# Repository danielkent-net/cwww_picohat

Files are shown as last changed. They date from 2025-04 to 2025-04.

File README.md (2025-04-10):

# cwww\_picohat: Pi Pico based Dual Cool/Warm LED Lamp Controller

A Raspberry Pi Pico/Pi Pico W based controller for dual cool white / warm
white common anode LED lamps.

|KiCAD Render | Assembled Version|
|---|---|
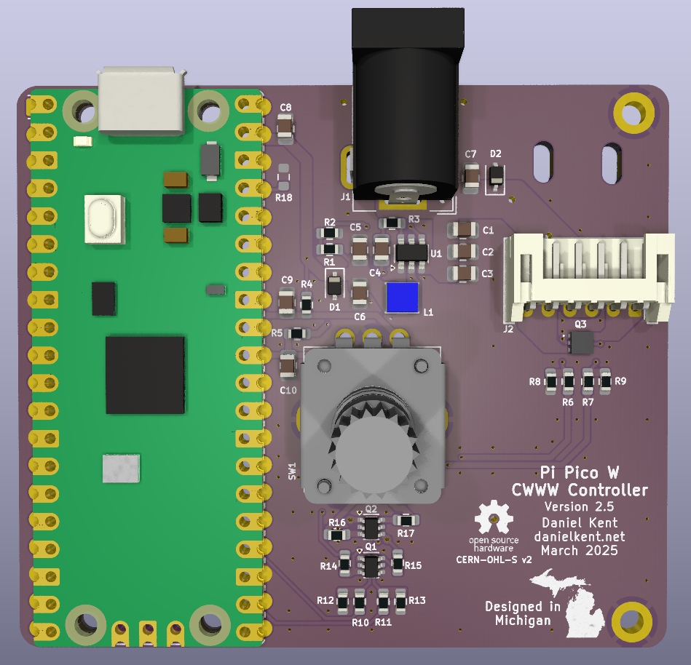
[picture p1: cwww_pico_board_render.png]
Render of the CWWW Pico LED controller, board variant
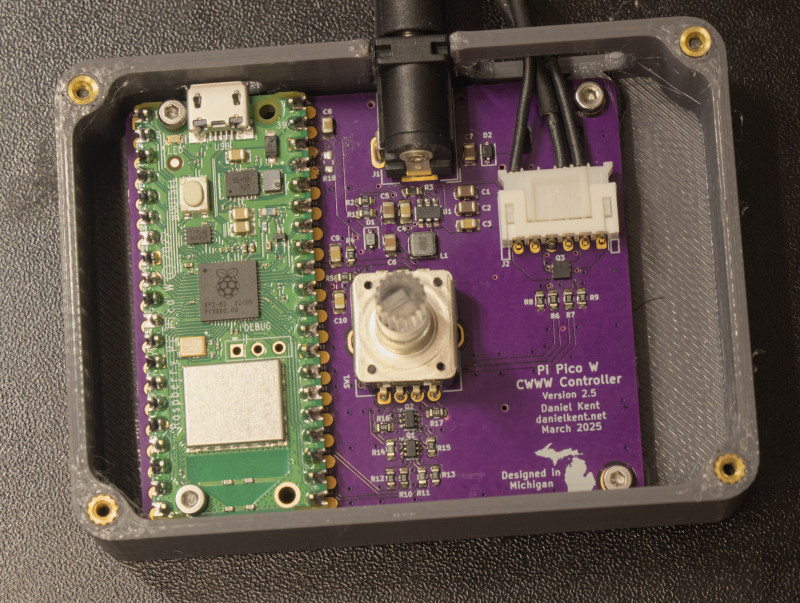
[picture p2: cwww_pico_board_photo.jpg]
Photograph of CWWW Pico LED controller, board variant
|  |  |

This repository contains two variants: the original "hat" based design, which
is smaller and contains a connector for a dedicated user I/O board, and a
larger "board" variant that puts everything on a flat board. The board
variant is a much more mature design and is recommended if you want to try
making this yourself.

This board was designed to work with
[ESPHome](https://github.com/esphome/esphome), but could be easily programmed
with other software tools.

# License

[The hardware is licensed under the CERN Open Hardware License Version
2 - Strongly Reciprocal](LICENSE).

[ESPHome configurations are licensed under the MIT license](LICENSE-SW).

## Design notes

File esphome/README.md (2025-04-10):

# ESPHome configurations for CWWW Pico Hat/Board

Note: the CWWW Pico Hat configuration has not been tested, as that design has
been retired. Use at your own risk.

Remember to edit or replace secrets.yaml.

These configurations were tested on the esphome version 2024.12.4.

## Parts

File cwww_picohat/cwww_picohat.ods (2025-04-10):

Source: | /home/silver/Projects/cwww_picohat/cwww_picohat/cwww_picohat.kicad_sch
Date: | Tue 07 Feb 2023 07:38:26 PM EST
Tool: | Eeschema 6.0.2+dfsg-1
Generator: | /usr/share/kicad/plugins/bom_csv_grouped_by_value_with_fp.py
Component Count Ea: | 32
Board Count | 2
Ref | Qnty Per | Qnty Total | Cost Ea. | Cost Total | Value | Cmp name | Footprint | Description | Vendor | URL
C1, C2, C7, C1b | 4 | 8 | $0.20 | $1.60 | 10uF | C | Capacitor_SMD:C_0805_2012Metric_Pad1.18x1.45mm_HandSolder | 10uF 0805 Unpolarized Capactitor | Digikey | https://www.digikey.com/en/products/detail/samsung-electro-mechanics/CL21A106KAFN3NE/3888548
C3, | 1 | 2 | $0.23 | $0.46 | 1uF | C | Capacitor_SMD:C_0805_2012Metric_Pad1.18x1.45mm_HandSolder | 1uF 0805 Unpolarized Capactitor | Digikey | https://www.digikey.com/en/products/detail/kyocera-avx/08053C105MAT4A/8107686
C4, | 1 | 2 | $0.10 | $0.20 | .1uF | C | Capacitor_SMD:C_0603_1608Metric_Pad1.08x0.95mm_HandSolder | .1uF 0805 Unpolarized Capactitor | Digikey | https://www.digikey.com/en/products/detail/kyocera-avx/08055C104KAT4A/6816312
C5, C6, | 2 | 4 | $0.33 | $1.32 | 22uF | C | Capacitor_SMD:C_0805_2012Metric_Pad1.18x1.45mm_HandSolder | 22uF 0805 Unpolarized Capactitor | Digikey | https://www.digikey.com/en/products/detail/samsung-electro-mechanics/CL21A226KOQNNNG/3894433
J1, | 1 | 2 | $0.17 | $0.34 | Conn_01x02 | Conn_01x02 | Connector_JST:JST_PH_S2B-PH-K_1x02_P2.00mm_Horizontal | JST PH Connector, 2mm Pitch, Horizontal, 2 Pin | Digikey | https://www.digikey.com/en/products/detail/jst-sales-america-inc/S2B-PH-K-S-LF-SN/926626
J2, | 1 | 2 | $0.31 | $0.62 | Conn_01x06 | Conn_01x06 | Connector_JST:JST_PH_S6B-PH-K_1x06_P2.00mm_Horizontal | JST PH Connector, 2mm Pitch, Horizontal, 6 Pin | Digikey | https://www.digikey.com/en/products/detail/jst-sales-america-inc/S6B-PH-K-S-LF-SN/926630
J3, J1b | 2 | 4 | $0.36 | $1.44 | Conn_01x06 | Conn_01x06 | Connector_JST:JST_PH_B6B-PH-K_1x06_P2.00mm_Vertical | JST PH Connector, 2mm Pitch, Vertical, 6 Pin | Digikey | https://www.digikey.com/en/products/detail/jst-sales-america-inc/B6B-PH-K-S-LF-SN/926615
L1, | 1 | 2 | $0.61 | $1.22 | 2.2uH | L | Inductor_SMD:L_1210_3225Metric_Pad1.42x2.65mm_HandSolder | 2.2uH 1210 Inductor | Digikey | https://www.digikey.com/en/products/detail/murata-electronics/LQM31PN2R2M00L/2594617
Q1, Q2, | 2 | 4 | $0.44 | $1.76 | NXV55UN | Q_NMOS_DSG | Package_TO_SOT_SMD:SOT-23 | NXV55UN N-MOSFET transistor, drain/source/gate | Digikey | https://www.digikey.com/en/products/detail/murata-electronics/DFE322512F-2R2M-P2/9815914
R1 | 1 | 2 | $0.10 | $0.20 | 33.2k | R | Resistor_SMD:R_0603_1608Metric_Pad0.98x0.95mm_HandSolder | 33.2 kOhm 0603 Resistor | Digikey | https://www.digikey.com/en/products/detail/panasonic-electronic-components/ERJ-3EKF3322V/196299
R2, R4, R6 | 3 | 6 | $0.10 | $0.60 | 10k | R | Resistor_SMD:R_0603_1608Metric_Pad0.98x0.95mm_HandSolder | 10 kOhm 0603 Resistor | Digikey | https://www.digikey.com/en/products/detail/panasonic-electronic-components/ERJ-3EKF1002V/196066
R4, R5 | 2 | 4 | $0.10 | $0.40 | 10 | R | Resistor_SMD:R_0603_1608Metric_Pad0.98x0.95mm_HandSolder | 10 Ohm 0603 Resistor | Digikey | https://www.digikey.com/en/products/detail/panasonic-electronic-components/ERJ-3EKF10R0V/196065
U2, | 1 | 2 | $1.49 | $2.98 | TPS565201 | TPS565208 | Package_TO_SOT_SMD:SOT-23-6 | TPS565208 5A Voltage Regulator, SOT-23-6 | Digikey | https://www.digikey.com/en/products/detail/texas-instruments/TPS565208DDCR/7776393
SW1, SW2, SW3, SW4, | 4 | 8 | $0.35 | $2.80 | SW_Push | SW_Push | Button_Switch_SMD:SW_Push_1P1T_NO_6x6mm_H9.5mm | Push button switch, generic, two pins | Digikey | https://www.digikey.com/en/products/detail/te-connectivity-alcoswitch-switches/FSM6JSMA/525822
PCB1 | 1 | 2 | $2.50 | $5.00 | CWWW_Hat PCB | Pico_Base_Hat_Antenna_Gap | picolamp:Partial Pico Hat with Antenna Gap | Pi Pico W CWWW Hat PCB | OSHPark
Mask1 | 1 | 1 |  | $0.00
PCB2 | 1 | 2 | $1.42 | $2.83 | CWWW_Buttons PCB |  |  | Pi Pico W CWWW Buttons Board PCB | OSHPark
Mask2 | 1 | 1 |  | $0.00
Pins_Pico | 1 | 2 | $1.75 | $3.50
Pins_Hat | 1 | 2 | $1.75 | $3.50 |  |  |  |  | Sparkfun | https://www.sparkfun.com/products/115
 |  |  | Total | $23.77 |  |  |  |  | Sparkfun | https://www.sparkfun.com/products/17907
 |  |  | Total Ea | $11.89

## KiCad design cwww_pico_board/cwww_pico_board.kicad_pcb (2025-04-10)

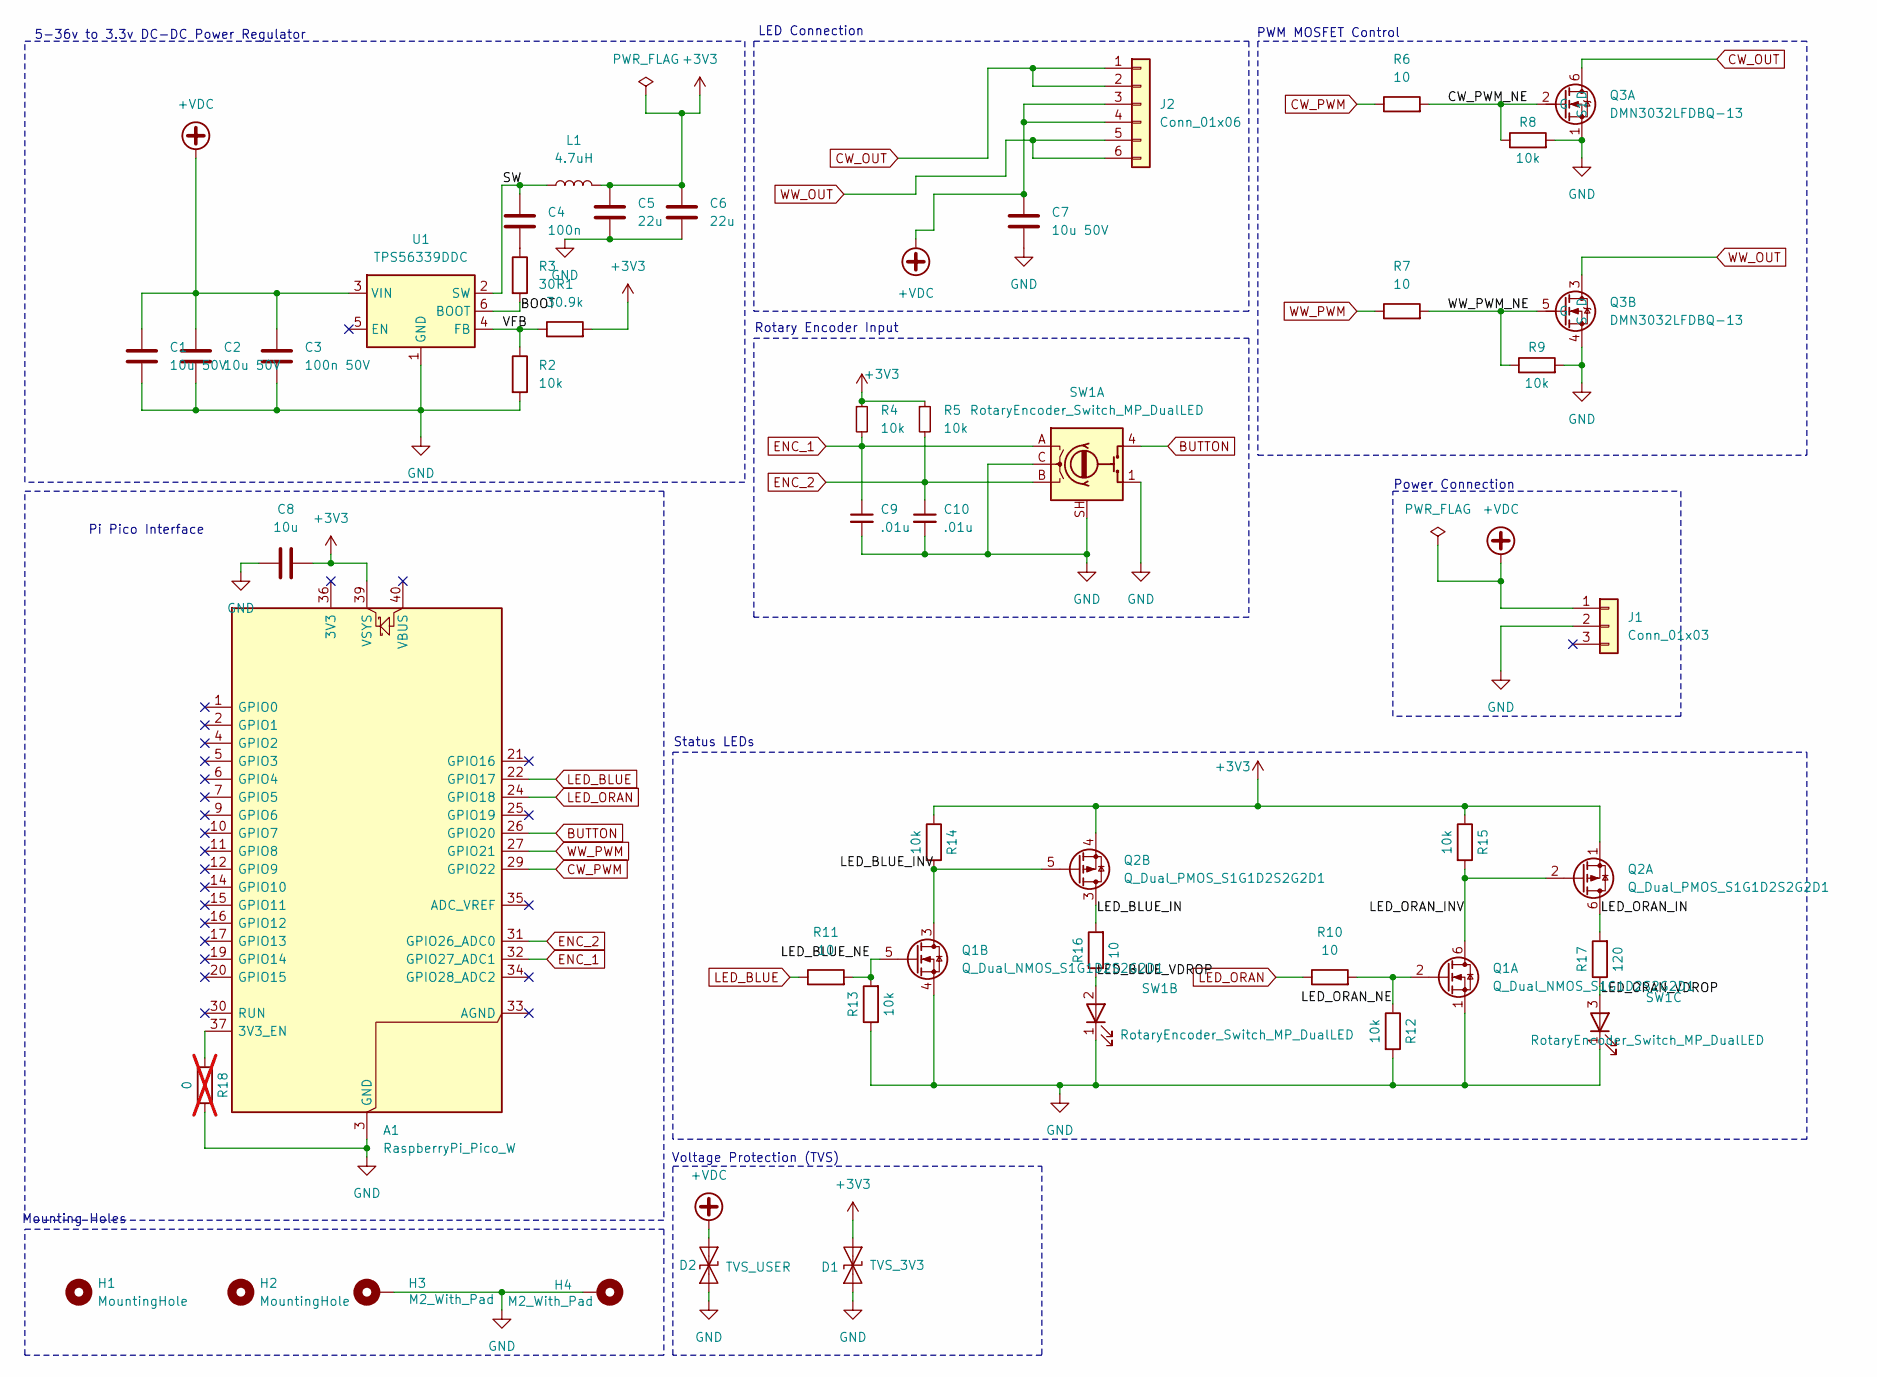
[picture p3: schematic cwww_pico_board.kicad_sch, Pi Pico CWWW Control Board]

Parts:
A1: RaspberryPi_Pico_W; RaspberryPi_Pico_Common_MountingHoles
C1, C2, C7: 10u 50V; C_0805_2012Metric
C3: 100n 50V; C_0805_2012Metric
C4: 100n; C_0805_2012Metric
C5, C6: 22u; C_0805_2012Metric
C8: 10u; C_0805_2012Metric
C9, C10: .01u; C_0805_2012Metric
D1: TVS_3V3; D_SOD-323
D2: TVS_USER; D_SOD-323
H1, H2: MountingHole; ZipTieHole_3.8mm
H3, H4: M2_With_Pad; MountingHole_2.2mm_M2_DIN965_Pad
J1: Conn_01x03; BarrelJack_Wuerth_6941xx301002_ShortOverhang
J2: Conn_01x06; JST_PH_S6B-PH-K_1x06_P2.00mm_Horizontal
L1: 4.7uH; INDPM3015X150N
Q1: Q_Dual_NMOS_S1G1D2S2G2D1
Q2: Q_Dual_PMOS_S1G1D2S2G2D1; SOT-363_SC-70-6
Q3: DMN3032LFDBQ-13; DMN3032LFDBQ13_OSHPark; Mouser Part Number 621-DMN3032LFDBQ-13
R1: 30.9k; R_0603_1608Metric
R2, R4, R5, R8, R9, R12, R13, R14, R15: 10k; R_0603_1608Metric
R3: 30; R_0603_1608Metric
R6, R7, R10, R11, R16: 10; R_0603_1608Metric
R17: 120; R_0603_1608Metric
R18: 0; R_0603_1608Metric; not fitted
SW1: RotaryEncoder_Switch_MP_DualLED; RotaryEncoder_Bourns_Vertical_PEL12D-4xxxF-Sxxxx
U1: TPS56339DDC; SOT-23-6

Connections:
+3V3: A1.39 (VSYS), C5.1, C6.1, C8.1, D1.1 (A1), L1.2, Q2.1 (S), Q2.4 (S), R1.2, R4.1, R5.1, R14.1, R15.1
+VDC: C1.1, C2.1, C3.1, C7.1, D2.1 (A1), J1.1, J2.3, J2.4, U1.3 (VIN)
/BOOT: R3.2, U1.6 (BOOT)
/CW_PWM_NE: Q3.2 (G), R6.2, R8.1
/LED_BLUE_IN: Q2.3 (D), R16.2
/LED_BLUE_INV: Q1.3 (D), Q2.5 (G), R14.2
/LED_BLUE_NE: Q1.5 (G), R11.2, R13.2
/LED_BLUE_VDROP: R16.1, SW1.2 (A_LED1)
/LED_ORAN_IN: Q2.6 (D), R17.2
/LED_ORAN_INV: Q1.6 (D), Q2.2 (G), R15.2
/LED_ORAN_NE: Q1.2 (G), R10.2, R12.1
/LED_ORAN_VDROP: R17.1, SW1.3 (A_LED2)
/SW: C4.1, L1.1, U1.2 (SW)
/VFB: R1.1, R2.1, U1.4 (FB)
/WW_PWM_NE: Q3.5 (G), R7.2, R9.1
BUTTON: A1.26 (GPIO20), SW1.4 (S1)
CW_OUT: J2.1, J2.2, Q3.6 (D)
CW_PWM: A1.29 (GPIO22), R6.1
ENC_1: A1.32 (GPIO27_ADC1), C9.1, R4.2, SW1.A
ENC_2: A1.31 (GPIO26_ADC0), C10.1, R5.2, SW1.B
GND: A1.3 (GND), A1.8 (GND), A1.13 (GND), A1.18 (GND), A1.23 (GND), A1.28 (GND), A1.38 (GND), C1.2, C2.2, C3.2, C5.2, C6.2, C7.2, C8.2, C9.2, C10.2, D1.2 (A2), D2.2 (A2), H3.1, H4.1, J1.2, Q1.1 (S), Q1.4 (S), Q3.1 (S1), Q3.4 (S), R2.2, R8.2, R9.2, R12.2, R13.1, R18.2, SW1.1 (GND), SW1.C, SW1.SH (MP), U1.1 (GND)
LED_BLUE: A1.22 (GPIO17), R11.1
LED_ORAN: A1.24 (GPIO18), R10.1
unnamed: A1.37 (3V3_EN), R18.1
unnamed: C4.2, R3.1
WW_OUT: J2.5, J2.6, Q3.3 (D)
WW_PWM: A1.27 (GPIO21), R7.1

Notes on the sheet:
Power Connection
5-36v to 3.3v DC-DC Power Regulator
PWM MOSFET Control
Pi Pico Interface
LED Connection
Mounting Holes
Rotary Encoder Input
Voltage Protection (TVS)
Status LEDs

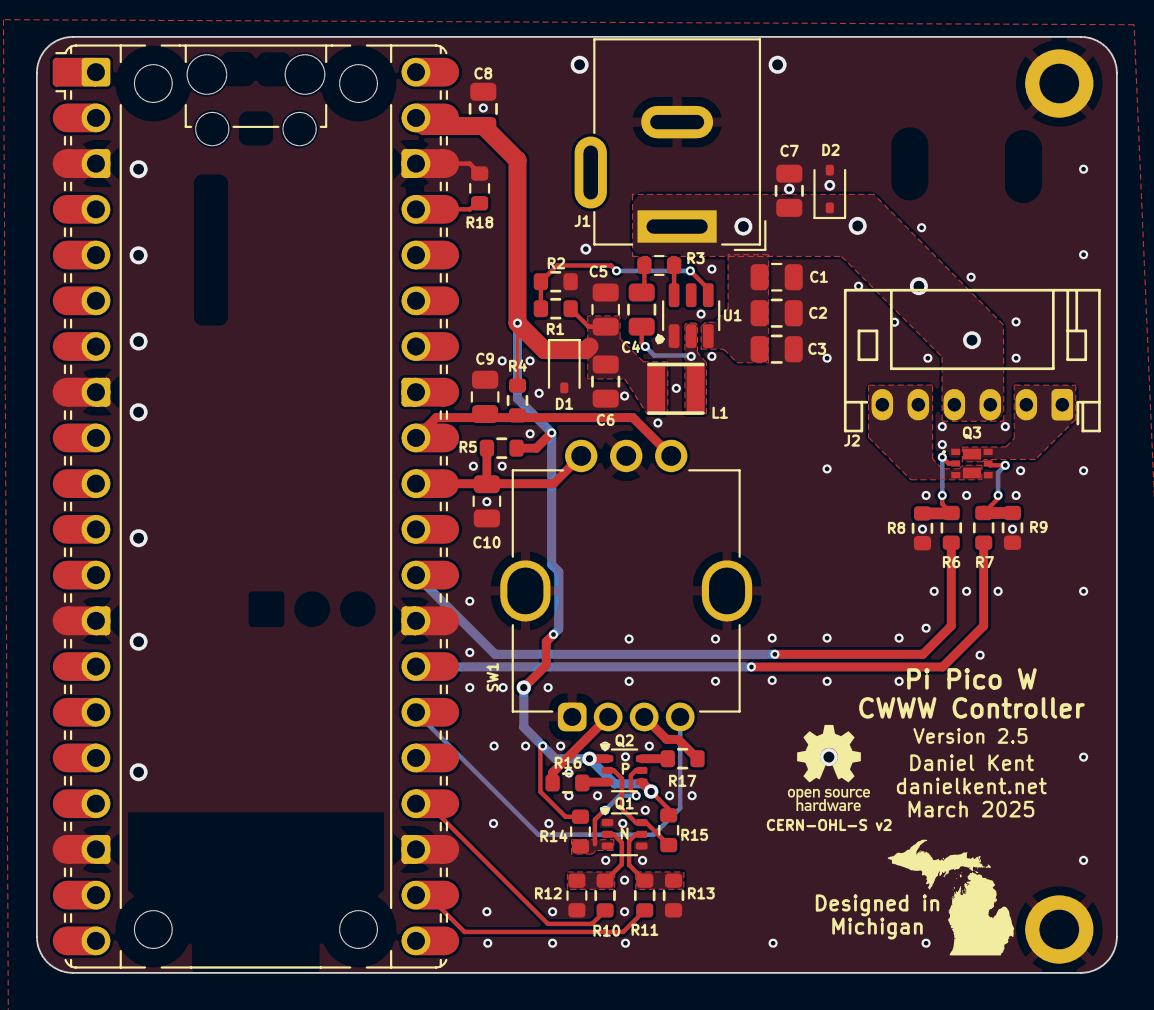
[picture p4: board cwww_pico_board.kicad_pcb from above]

Board: 2 copper layers, 60.0 x 52.0 mm, 43 parts (0 on the bottom side), 27 nets.

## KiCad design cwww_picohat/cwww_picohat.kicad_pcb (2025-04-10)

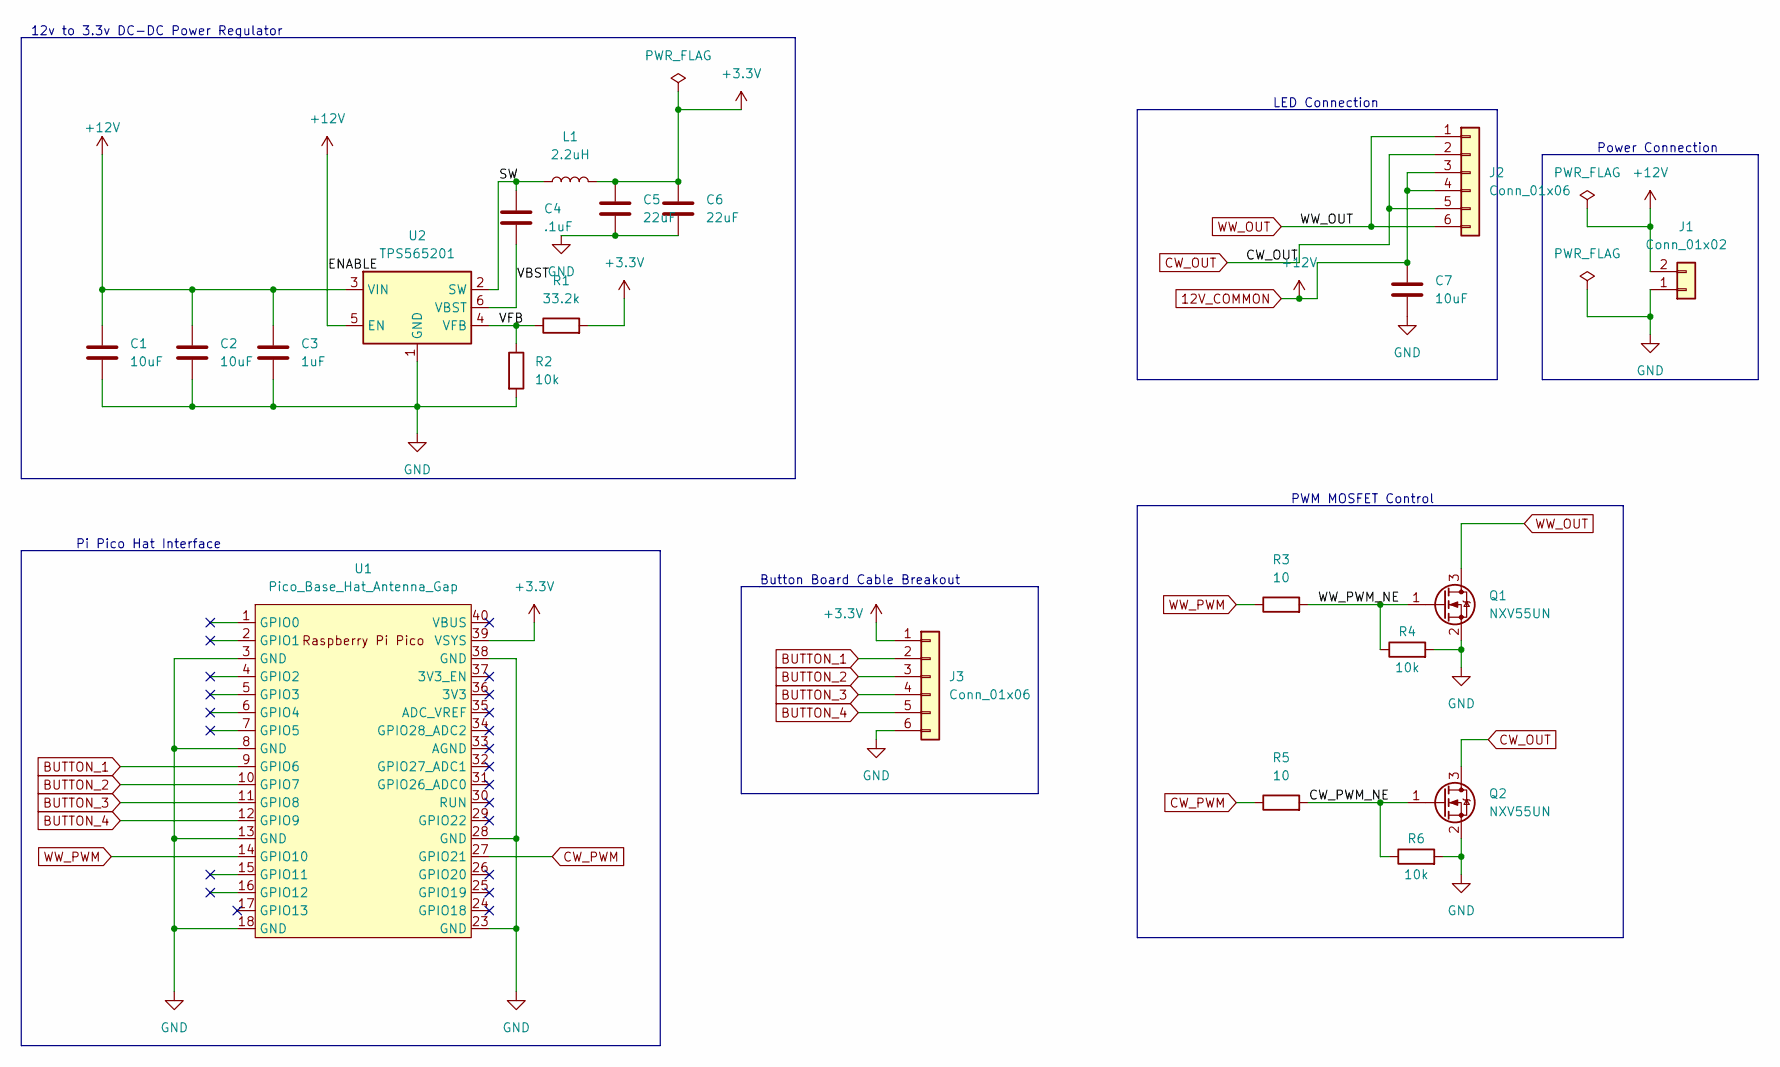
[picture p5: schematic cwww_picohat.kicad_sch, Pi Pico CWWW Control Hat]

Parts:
C1, C2, C7: 10uF; C_0805_2012Metric_Pad1.18x1.45mm_HandSolder
C3: 1uF; C_0805_2012Metric_Pad1.18x1.45mm_HandSolder
C4: .1uF; C_0603_1608Metric_Pad1.08x0.95mm_HandSolder
C5, C6: 22uF; C_0805_2012Metric_Pad1.18x1.45mm_HandSolder
J1: Conn_01x02; JST_PH_S2B-PH-K_1x02_P2.00mm_Horizontal
J2: Conn_01x06; JST_PH_S6B-PH-K_1x06_P2.00mm_Horizontal
J3: Conn_01x06; JST_PH_B6B-PH-K_1x06_P2.00mm_Vertical
L1: 2.2uH; L_1210_3225Metric_Pad1.42x2.65mm_HandSolder
Q1, Q2: NXV55UN; SOT-23-3
R1: 33.2k; R_0603_1608Metric_Pad0.98x0.95mm_HandSolder
R2, R4, R6: 10k; R_0603_1608Metric_Pad0.98x0.95mm_HandSolder
R3, R5: 10; R_0603_1608Metric_Pad0.98x0.95mm_HandSolder
U1: Pico_Base_Hat_Antenna_Gap; Partial Pico Hat with Antenna Gap
U2: TPS565201; SOT-23-6

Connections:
12V_COMMON: C1.1, C2.1, C3.1, C7.1, J1.2, J2.3, J2.4, U2.3 (VIN), U2.5 (EN)
+3V3: C5.1, C6.1, J3.1, L1.2, R1.2, U1.39 (VSYS)
/CW_PWM_NE: Q2.1 (G), R5.2, R6.1
/SW: C4.1, L1.1, U2.2 (SW)
/VBST: C4.2, U2.6 (VBST)
/VFB: R1.1, R2.1, U2.4 (VFB)
/WW_PWM_NE: Q1.1 (G), R3.2, R4.1
BUTTON_1: J3.2, U1.9 (GPIO6)
BUTTON_2: J3.3, U1.10 (GPIO7)
BUTTON_3: J3.4, U1.11 (GPIO8)
BUTTON_4: J3.5, U1.12 (GPIO9)
CW_OUT: J2.2, J2.5, Q2.3 (D)
CW_PWM: R5.1, U1.27 (GPIO21)
GND: C1.2, C2.2, C3.2, C5.2, C6.2, C7.2, J1.1, J3.6, Q1.2 (S), Q2.2 (S), R2.2, R4.2, R6.2, U1.3 (GND), U1.8 (GND), U1.13 (GND), U1.18 (GND), U1.23 (GND), U1.28 (GND), U1.38 (GND), U2.1 (GND)
WW_OUT: J2.1, J2.6, Q1.3 (D)
WW_PWM: R3.1, U1.14 (GPIO10)

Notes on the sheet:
Power Connection
12v to 3.3v DC-DC Power Regulator
PWM MOSFET Control
Pi Pico Hat Interface
LED Connection
Button Board Cable Breakout

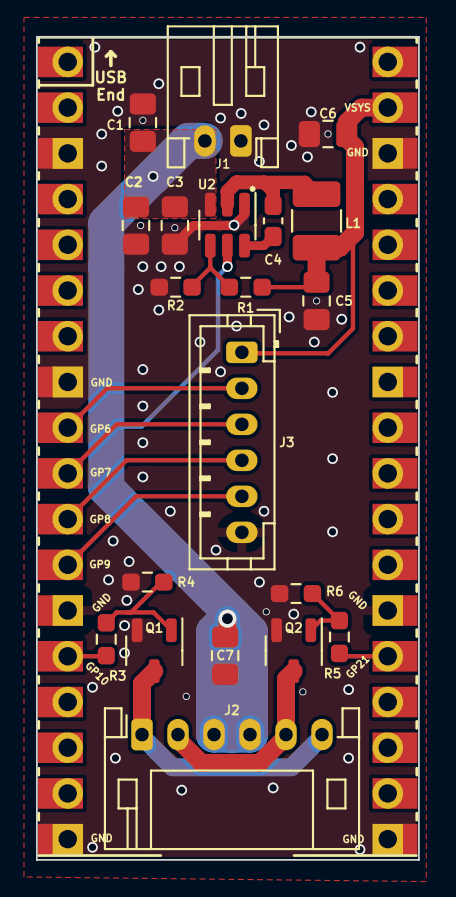
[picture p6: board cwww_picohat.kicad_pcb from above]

Board: 2 copper layers, 21.2 x 45.7 mm, 21 parts (0 on the bottom side), 16 nets.

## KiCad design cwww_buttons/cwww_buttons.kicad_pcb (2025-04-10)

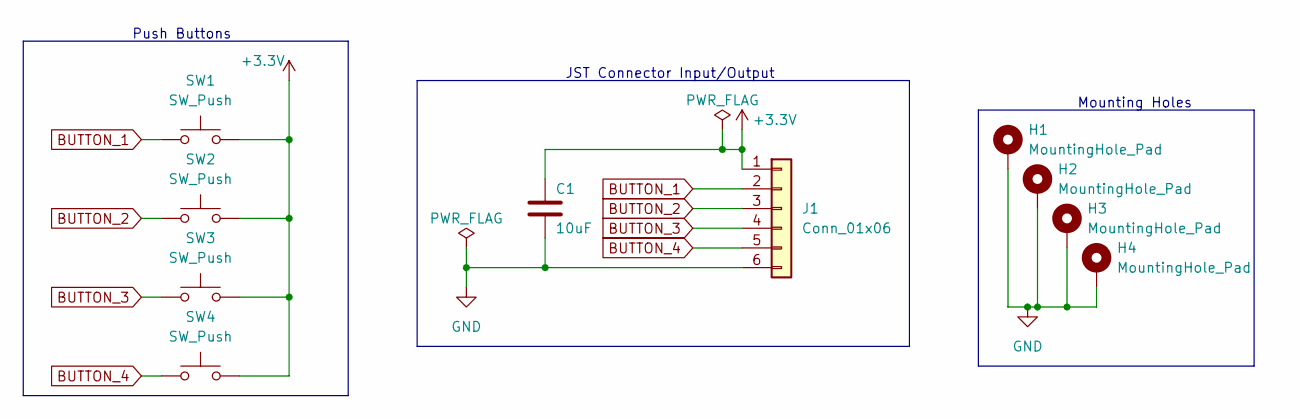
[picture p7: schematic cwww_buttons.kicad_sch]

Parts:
C1: 10uF; C_0805_2012Metric_Pad1.18x1.45mm_HandSolder
H1, H2, H3, H4: MountingHole_Pad; MountingHole_2.2mm_M2_DIN965_Pad
J1: Conn_01x06; JST_PH_B6B-PH-K_1x06_P2.00mm_Vertical
SW1, SW2, SW3, SW4: SW_Push; SW_Push_1P1T_NO_6x6mm_H9.5mm

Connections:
+3V3: C1.1, J1.1, SW1.2, SW2.2, SW3.2, SW4.2
BUTTON_1: J1.2, SW1.1
BUTTON_2: J1.3, SW2.1
BUTTON_3: J1.4, SW3.1
BUTTON_4: J1.5, SW4.1
GND: C1.2, H1.1, H2.1, H3.1, H4.1, J1.6

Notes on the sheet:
Mounting Holes
JST Connector Input/Output
Push Buttons

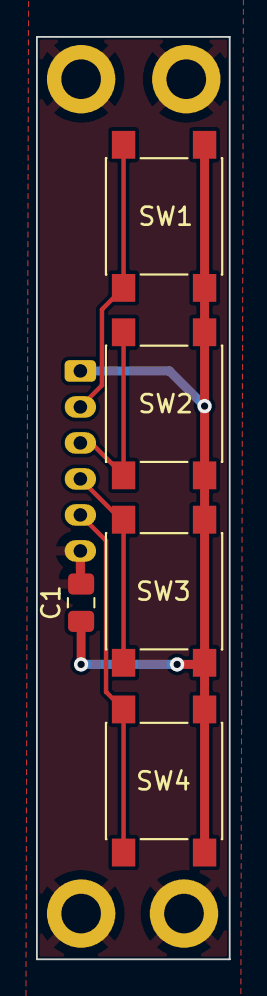
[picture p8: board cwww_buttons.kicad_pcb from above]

Board: 2 copper layers, 10.7 x 51.2 mm, 10 parts (1 on the bottom side), 6 nets.

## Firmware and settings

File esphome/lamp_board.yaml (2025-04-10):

# Copyright (c) 2025 Daniel Kent
#
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
# CWWW ESPHome configuration - Board Variant

substitutions:
  lampname: desklamp
  lamp_name: desk_lamp
  human_lamp_name: "Desk Lamp"
  color_step: '2.25'
  color_min: '166.66666'
  color_max: '333.33333'
  pwm_rate: '50000Hz'
  pwm_encoder_rate: '200Hz'

esphome:
  name: ${lampname}
  comment: ${human_lamp_name}
  
logger:
  level: DEBUG
  baud_rate: 115200
  
rp2040:
  board: rpipicow
  
wifi:
  ssid: !secret wifi_ssid
  password: !secret wifi_password
  reboot_timeout: 0s
  ap:
    ssid: "${lampname}_fallback"
    password: !secret wifi_fallback_password
    ap_timeout: 120min

      
api:
  encryption:
    key: !secret encryption_key
  id: ${lampname}

ota:
  platform: esphome
  password: !secret ota_password

globals:
  - id: redshift
    type: bool
    restore_value: no
    initial_value: 'false'

light:
  - platform: cwww
    name: ${human_lamp_name}
    id: ${lamp_name}
    cold_white: cool_pin
    warm_white: warm_pin
    cold_white_color_temperature: 6000 K
    warm_white_color_temperature: 3000 K 
    constant_brightness: true

  - platform: cwww
    name: "${human_lamp_name} Encoder Light"
    id: ${lamp_name}_encoder_light
    internal: true
    cold_white: enc_pin_blue
    warm_white: enc_pin_oran
    cold_white_color_temperature: 6000 K
    warm_white_color_temperature: 3000 K 
    constant_brightness: true

sensor:
   - platform: rotary_encoder
     name: "Rotary Encoder"
     id: ${lamp_name}_encoder
     resolution: 1
     pin_a: 27
     pin_b: 26
     on_clockwise:
       then:
         - if:
             condition:
               and:
                 - light.is_on: ${lamp_name}
                 - lambda: 'return (id(redshift) == true);'
             then:
               - light.turn_on:
                   id: ${lamp_name}
                   color_temperature: !lambda 'return id(${lamp_name}).remote_values.get_color_temperature() - ${color_step};'
                   transition_length: 200ms
         - if:
             condition:
               and:
                 - light.is_on: ${lamp_name}
                 - lambda: 'return (id(redshift) == false);'
             then:
               - light.dim_relative:
                   id: ${lamp_name}
                   relative_brightness: 2%
                   transition_length: 200ms
                   brightness_limits:
                     max_brightness: 100%
                     min_brightness: 5%
                     limit_mode: CLAMP
               - script.execute:
                   id: enc_led_sync_short
             else:
                - light.turn_on:
                    id: ${lamp_name}
                    transition_length: 500ms
                - script.execute:
                    id: enc_led_sync

         - script.execute: idle_reset

     on_anticlockwise:
       then:
         - if:
             condition:
               and:
                 - light.is_on: ${lamp_name}
                 - lambda: 'return (id(redshift) == true);'
             then:
               - light.turn_on:
                   id: ${lamp_name}
                   color_temperature: !lambda 'return id(${lamp_name}).remote_values.get_color_temperature() + ${color_step};'
                   transition_length: 200ms
         - if:
             condition:
               and:
                 - light.is_on: ${lamp_name}
                 - lambda: 'return (id(redshift) == false);'
             then:
               - light.dim_relative:
                   id: ${lamp_name}
                   relative_brightness: -2%
                   transition_length: 200ms
                   brightness_limits:
                     max_brightness: 100%
                     min_brightness: 5%
                     limit_mode: CLAMP
               - script.execute:
                   id: enc_led_sync_short
             else:
               - light.turn_on:
                   id: ${lamp_name}
                   transition_length: 500ms
               - script.execute:
                   id: enc_led_sync

         - script.execute: idle_reset
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

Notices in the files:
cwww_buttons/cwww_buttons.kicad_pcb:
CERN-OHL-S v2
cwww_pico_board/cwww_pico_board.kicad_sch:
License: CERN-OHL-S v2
